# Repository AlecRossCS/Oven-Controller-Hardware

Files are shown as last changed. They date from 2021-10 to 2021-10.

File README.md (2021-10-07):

# Oven-Controller-Hardware
This project is about creating a controller for a heating element for a custom designed oven. The temperature needs to be controlled with industrial precision, so this baord contains a microcontroller as well as devices needed to interact with a thermocouple to precisely sense temperature, as well as a large power mosfet, which controls the power to the heating element to control the temperature with great accuracy. 

# Design

schematic

because of the supply shortage, the microcontroller was chosen as a RP2040 already made onto a Raspberry pi Pico board, because that board can be soldered onto another, as in this case, and both the RP2040, and my second choice of STM32F0 controllers are impossible to buy for any project currently. So buying a premade micro offers flexability as you can buy them in the quantities I need. the Micro interacts with both the sensor and mosfet, as well as capability to drive an LCD screen for display. A notable thing that is different here is that the mosfet does not use a large heatsink. That is not because it does not disspate much power, but because the newer technology on the market allows the Vishay thermal jumper to absorb and funnel much of the heat directly from the heat fin into the ground plane.

# Hardware
this was a standard layout, fairly straight forward. as components were placed and grouped, and then power connections ran, and then the rest of the connections, and then a gnd plane. 

the mockup

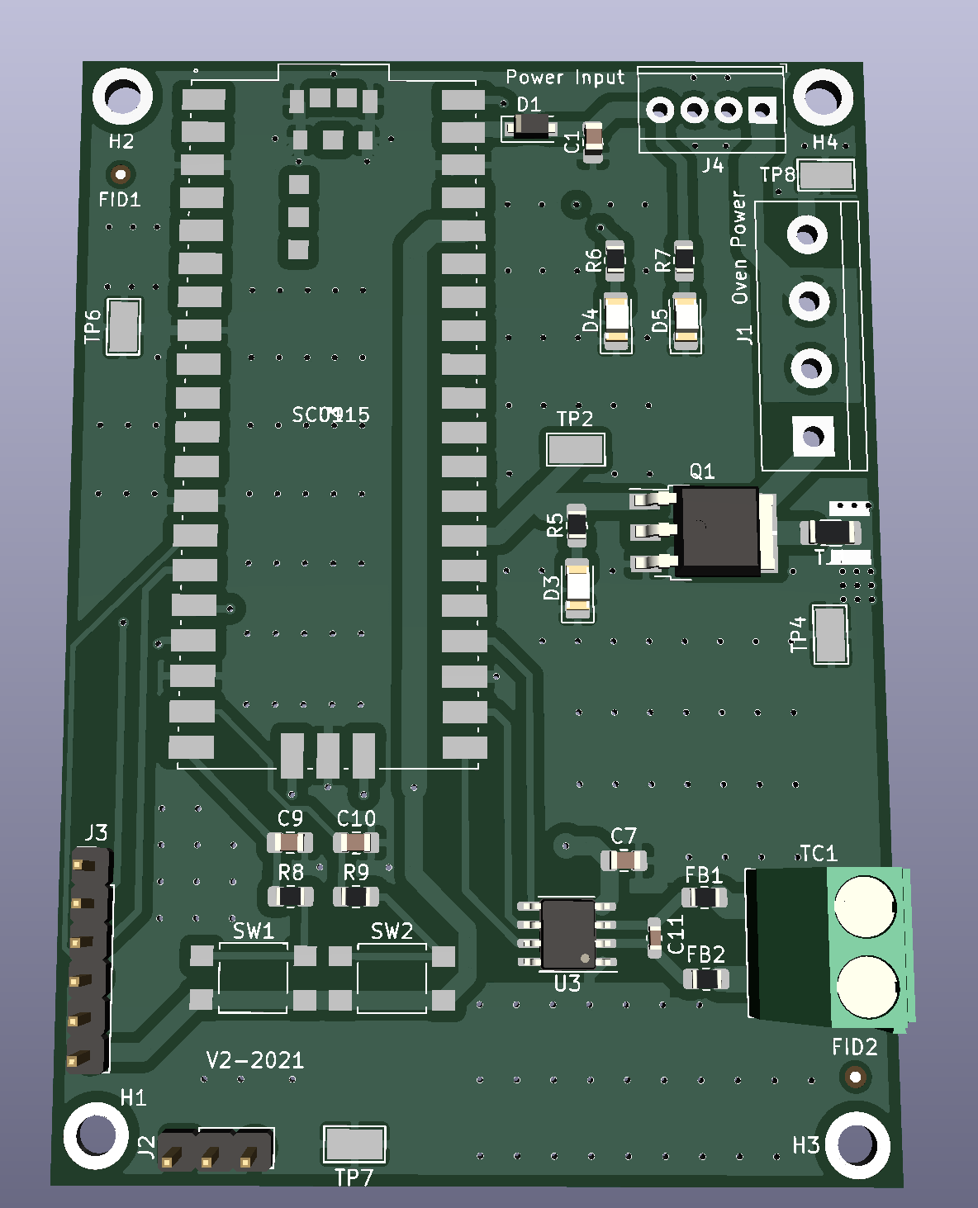
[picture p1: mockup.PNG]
mock


Version 1 has already been manufactured, and is currently in the firmware design stage. The major differences in design from version 1 is that it had SMPS on th board, which has now been broken into a separate board to allow for better space usage, a smaller footprint, and better thermal design for the SMPS.
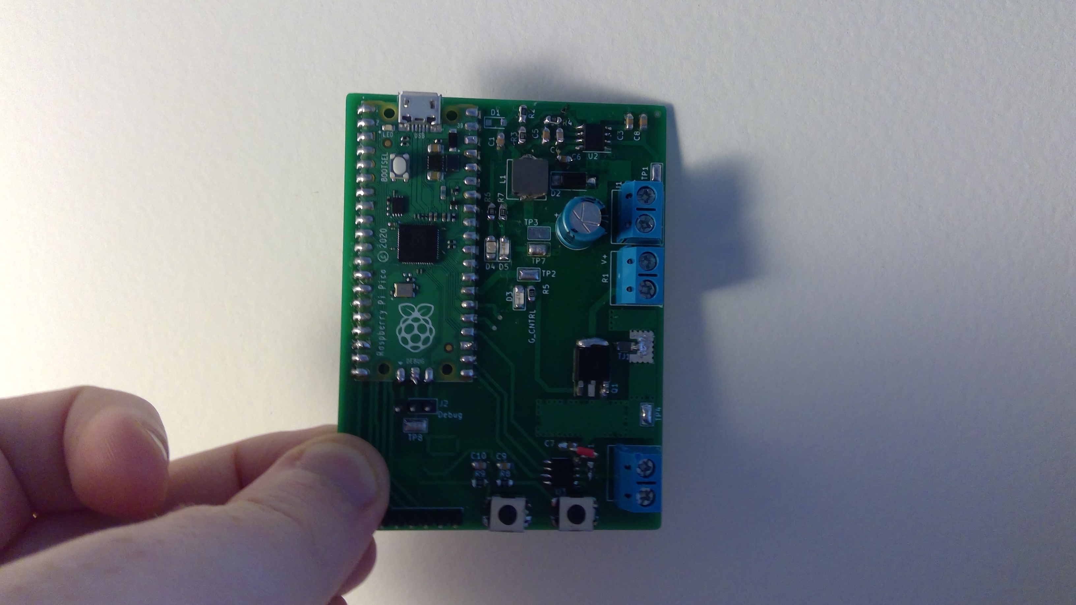
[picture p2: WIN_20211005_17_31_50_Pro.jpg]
actual_board


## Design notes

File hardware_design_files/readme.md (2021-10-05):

# hardware designfiles
all files designed in kicad, and simulated in Pspice.

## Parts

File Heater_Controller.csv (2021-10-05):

Source: | C:\Users\Alec\Documents\Classes\Electrical_Projects\Heater\Heater_Controller\Heater_Controller\Heater_Controller.sch
Date: | 8/18/2021 3:11
Tool: | Eeschema (5.1.10)-1
Generator: | C:\Program Files\KiCad\bin\scripting\plugins/bom_csv_grouped_by_value.py
Component Count: | 32
Individual Components:
Item | Qty | Reference(s) | Value | LibPart | Footprint | Datasheet | part#
0805B104J101CT | 1 | C1 | 100n | Device:C_Small | Capacitor_SMD:C_0805_2012Metric_Pad1.18x1.45mm_HandSolder | ~
25RX30100MCPA8X11.5 | 1 | C2 | 100u | Device:CP | Capacitor_THT:CP_Radial_D6.3mm_P2.50mm | ~
 |  | C3 | 5n | Device:C_Small | Capacitor_SMD:C_0805_2012Metric_Pad1.18x1.45mm_HandSolder | ~
 |  | C4 | 10p | Device:C_Small | Capacitor_SMD:C_0805_2012Metric_Pad1.18x1.45mm_HandSolder | ~
CGA4F2X7R2A222KT0Y0S | 5 | C5 | 2n | Device:C_Small | Capacitor_SMD:C_0805_2012Metric_Pad1.18x1.45mm_HandSolder | ~
0805B104J101CT | 1 | C6 | 100n | Device:C_Small | Capacitor_SMD:C_0805_2012Metric_Pad1.18x1.45mm_HandSolder | ~
0805B104J101CT | 1 | C7 | 100n | Device:C_Small | Capacitor_SMD:C_0805_2012Metric_Pad1.18x1.45mm_HandSolder | ~
0805B104J101CT | 1 | C8 | 100n | Device:C_Small | Capacitor_SMD:C_0805_2012Metric_Pad1.18x1.45mm_HandSolder | ~
US1DWF-7 | 1 | D1 | FS14 | Device:D_Schottky | Diode_SMD:D_SOD-123F | ~
SL34A-TP | 1 | D2 | SL34A | Device:D_Schottky | Diode_SMD:D_SMA_Handsoldering | ~
 |  | D3 | L171L-GC | Device:LED | LED_SMD:LED_0805_2012Metric_Pad1.15x1.40mm_HandSolder | ~
 |  | D4 | APTB1612SURKQBDC-F01 | Device:LED_Dual_AAC | LED_SMD:LED_Kingbright_AAA3528ESGCT | ~
FH1-200CK-B | 1 | F1 | Fuse | Device:Fuse | Fuse:Fuseholder_Cylinder-5x20mm_Stelvio-Kontek_PTF78_Horizontal_Open | ~
C4658 | 10 | HS1 | Heatsink_Pad | Mechanical:Heatsink_Pad | Heatsink:Heatsink_AAVID_573300D00010G_TO-263 | ~
C474881 | 5 | J1 | Screw_Terminal_01x02 | Connector:Screw_Terminal_01x02 | TerminalBlock_Phoenix:TerminalBlock_Phoenix_MKDS-1,5-2_1x02_P5.00mm_Horizontal | ~
5-146274-3 | 1 | J2 | Conn_01x03_Male | Connector:Conn_01x03_Male | Connector_PinHeader_2.54mm:PinHeader_1x03_P2.54mm_Vertical | ~
 |  | J3 | Conn_01x06 | Connector_Generic:Conn_01x06 | Connector_PinHeader_2.54mm:PinHeader_1x06_P2.54mm_Vertical | ~
 |  | L1 | 12uH | Device:L | Inductor_THT:L_Axial_L7.0mm_D3.3mm_P10.16mm_Horizontal_Fastron_MICC | ~
FDD8447L | 1 | Q1 | FDD8447L | Device:Q_NMOS_GDS | Package_TO_SOT_SMD:TO-252-3_TabPin2 | ~
RT0805FRE0710KL | 50 | R2 | 10k | Device:R | Resistor_SMD:R_0805_2012Metric_Pad1.20x1.40mm_HandSolder | ~
RT0805BRB072KL | 1 | R3 | 2k | Device:R | Resistor_SMD:R_0805_2012Metric_Pad1.20x1.40mm_HandSolder | ~
 | 1 | R4 | 14k | Device:R | Resistor_SMD:R_0805_2012Metric_Pad1.20x1.40mm_HandSolder | ~
ERA6AEB102V | 1 | R5 | 1k | Device:R | Resistor_SMD:R_0805_2012Metric_Pad1.20x1.40mm_HandSolder | ~
ERA6AEB102V | 1 | R6 | 1k | Device:R | Resistor_SMD:R_0805_2012Metric_Pad1.20x1.40mm_HandSolder | ~
ERA6AEB102V | 1 | R7 | 1k | Device:R | Resistor_SMD:R_0805_2012Metric_Pad1.20x1.40mm_HandSolder | ~
 | 2 | U1 | SC0915 | Heater_Controller-rescue:SC0915-2021-08-14_07-35-25 | footprints:SC0915-Up
TPS54331DR | 1 | U2 | TPS54331D | Heater_Controller-rescue:TPS54331D-2021-08-15_07-00-47 | Package_SO:SOIC-8_3.9x4.9mm_P1.27mm |  | TPS54331D
MAX31855KASA+T | 1 | U3 | MAX31855KASA | Sensor_Temperature:MAX31855KASA | Package_SO:SOIC-8_3.9x4.9mm_P1.27mm | http://datasheets.maximintegrated.com/en/ds/MAX31855.pdf
Collated Components:
Item | Qty | Reference(s) | Value | LibPart | Footprint | Datasheet | part#
1 | 4 | C1, C6, C7, C8 | 100n | Device:C_Small | Capacitor_SMD:C_0805_2012Metric_Pad1.18x1.45mm_HandSolder | ~
2 | 1 | C2 | 100u | Device:CP | Capacitor_THT:CP_Radial_D6.3mm_P2.50mm | ~
3 | 1 | C3 | 5n | Device:C_Small | Capacitor_SMD:C_0805_2012Metric_Pad1.18x1.45mm_HandSolder | ~
4 | 1 | C4 | 10p | Device:C_Small | Capacitor_SMD:C_0805_2012Metric_Pad1.18x1.45mm_HandSolder | ~
5 | 1 | C5 | 2n | Device:C_Small | Capacitor_SMD:C_0805_2012Metric_Pad1.18x1.45mm_HandSolder | ~
6 | 1 | D1 | FS14 | Device:D_Schottky | Diode_SMD:D_SOD-123F | ~
7 | 1 | D2 | SL34A | Device:D_Schottky | Diode_SMD:D_SMA_Handsoldering | ~
8 | 1 | D3 | L171L-GC | Device:LED | LED_SMD:LED_0805_2012Metric_Pad1.15x1.40mm_HandSolder | ~
9 | 1 | D4 | APTB1612SURKQBDC-F01 | Device:LED_Dual_AAC | LED_SMD:LED_Kingbright_AAA3528ESGCT | ~
10 | 1 | F1 | Fuse | Device:Fuse | Fuse:Fuseholder_Cylinder-5x20mm_Stelvio-Kontek_PTF78_Horizontal_Open | ~
11 | 2 | FID1, FID2 | Fiducial | Mechanical:Fiducial | Fiducial:Fiducial_0.75mm_Mask1.5mm | ~
12 | 1 | HS1 | Heatsink_Pad | Mechanical:Heatsink_Pad | Heatsink:Heatsink_AAVID_573300D00010G_TO-263 | ~
13 | 1 | J1 | Screw_Terminal_01x02 | Connector:Screw_Terminal_01x02 | TerminalBlock_Phoenix:TerminalBlock_Phoenix_MKDS-1,5-2_1x02_P5.00mm_Horizontal | ~
14 | 1 | J2 | Conn_01x03_Male | Connector:Conn_01x03_Male | Connector_PinHeader_2.54mm:PinHeader_1x03_P2.54mm_Vertical | ~
15 | 1 | J3 | Conn_01x06 | Connector_Generic:Conn_01x06 | Connector_PinHeader_2.54mm:PinHeader_1x06_P2.54mm_Vertical | ~
16 | 1 | L1 | 12uH | Device:L | Inductor_THT:L_Axial_L7.0mm_D3.3mm_P10.16mm_Horizontal_Fastron_MICC | ~
17 | 1 | Q1 | FDD8447L | Device:Q_NMOS_GDS | Package_TO_SOT_SMD:TO-252-3_TabPin2 | ~
18 | 1 | R1 | R | Device:R | TerminalBlock_Phoenix:TerminalBlock_Phoenix_MKDS-1,5-2_1x02_P5.00mm_Horizontal | ~
19 | 1 | R2 | 10k | Device:R | Resistor_SMD:R_0805_2012Metric_Pad1.20x1.40mm_HandSolder | ~
20 | 1 | R3 | 2k | Device:R | Resistor_SMD:R_0805_2012Metric_Pad1.20x1.40mm_HandSolder | ~
21 | 1 | R4 | 14k | Device:R | Resistor_SMD:R_0805_2012Metric_Pad1.20x1.40mm_HandSolder | ~
22 | 3 | R5, R6, R7 | 1k | Device:R | Resistor_SMD:R_0805_2012Metric_Pad1.20x1.40mm_HandSolder | ~
23 | 1 | TC1 | Thermocouple | Device:Thermocouple | TerminalBlock_Phoenix:TerminalBlock_Phoenix_MKDS-1,5-2_1x02_P5.00mm_Horizontal | ~
24 | 1 | U1 | SC0915 | Heater_Controller-rescue:SC0915-2021-08-14_07-35-25 | footprints:SC0915-Up
25 | 1 | U2 | TPS54331D | Heater_Controller-rescue:TPS54331D-2021-08-15_07-00-47 | Package_SO:SOIC-8_3.9x4.9mm_P1.27mm |  | TPS54331D
26 | 1 | U3 | MAX31855KASA | Sensor_Temperature:MAX31855KASA | Package_SO:SOIC-8_3.9x4.9mm_P1.27mm | http://datasheets.maximintegrated.com/en/ds/MAX31855.pdf

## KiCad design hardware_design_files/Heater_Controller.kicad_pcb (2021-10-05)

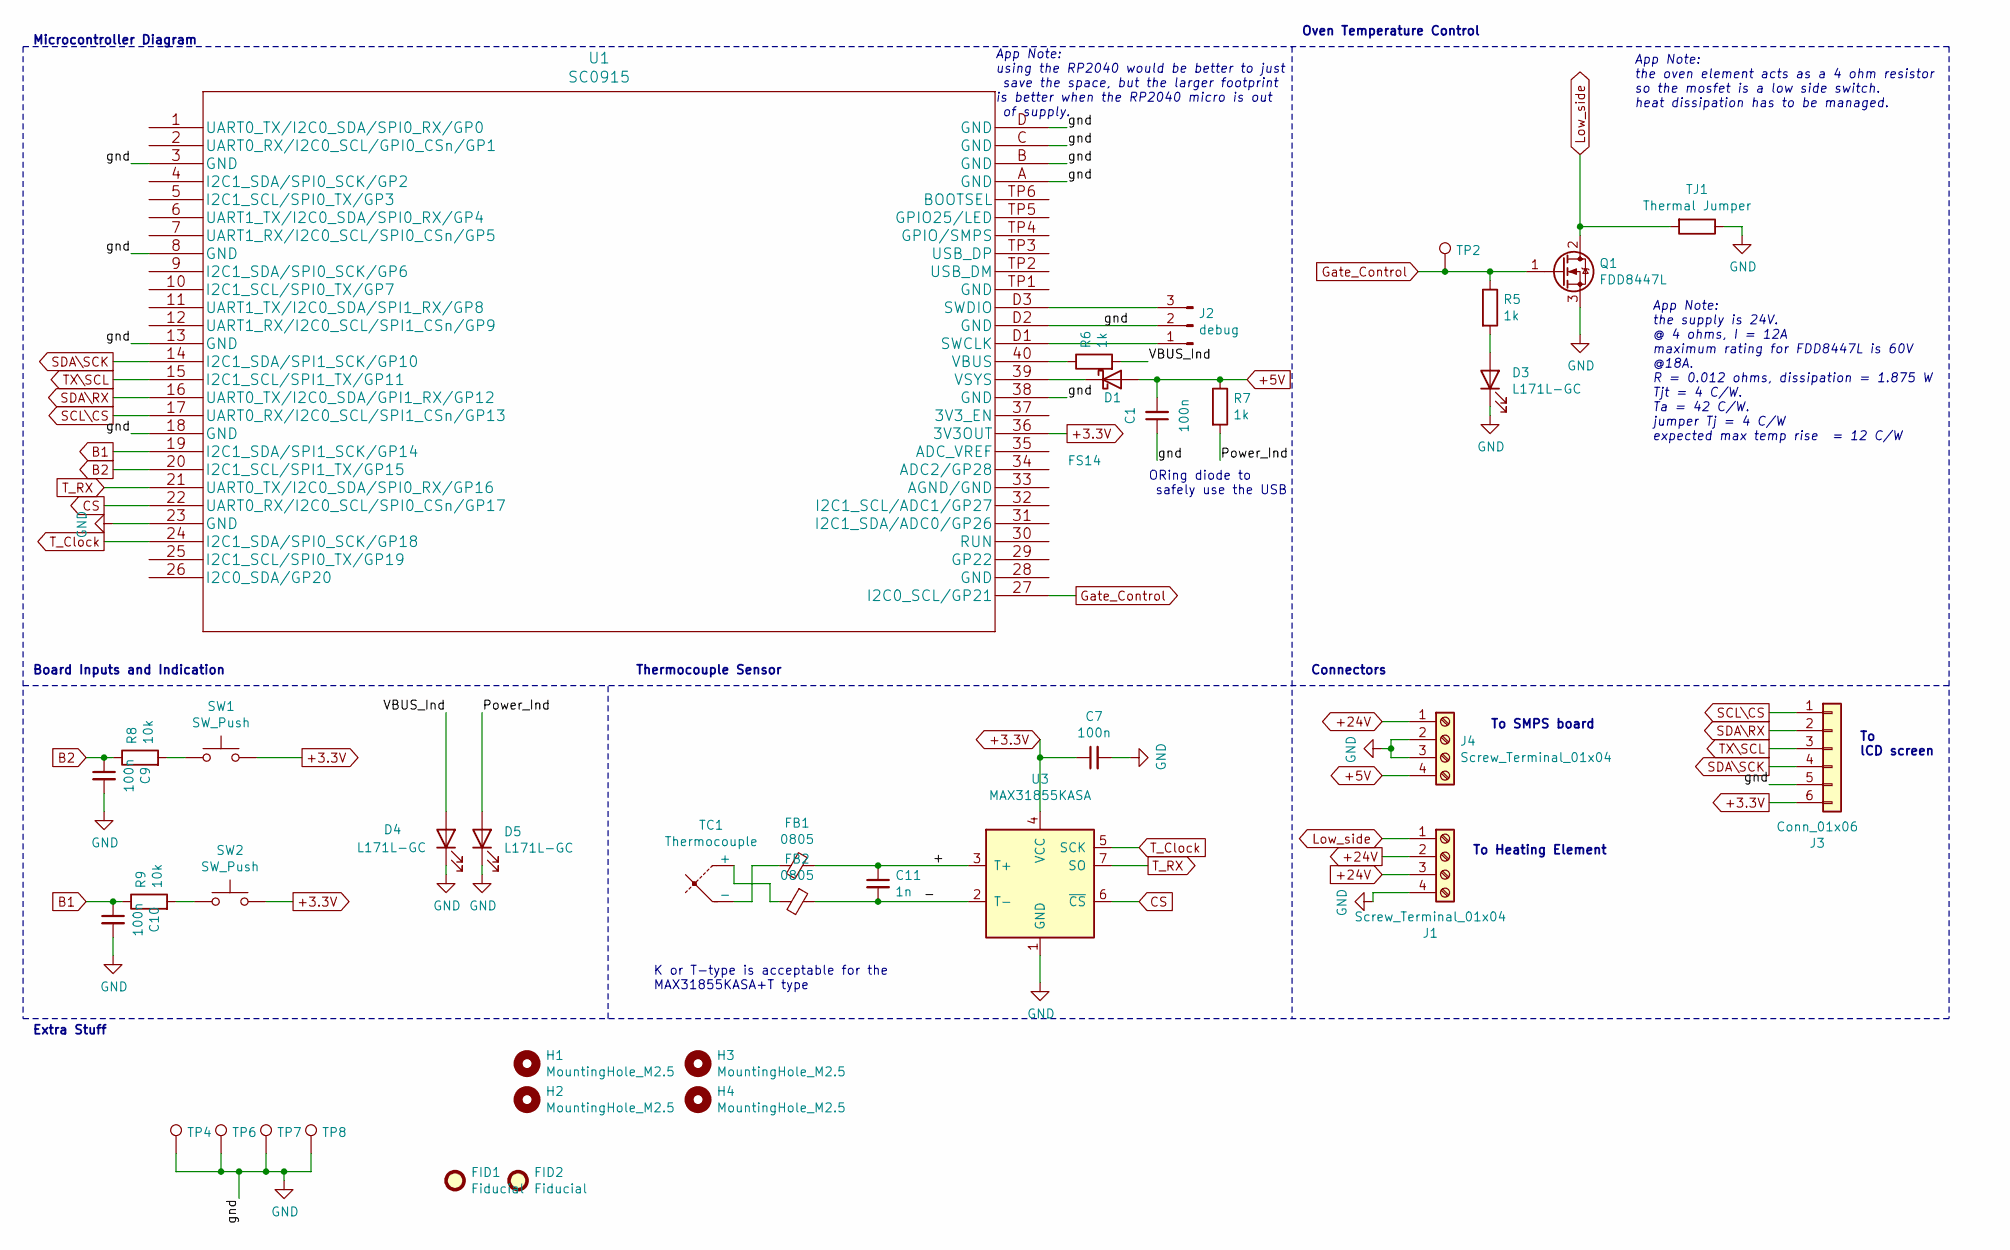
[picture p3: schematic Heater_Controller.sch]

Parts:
C1, C7, C9, C10: 100n; C_0805_2012Metric_Pad1.18x1.45mm_HandSolder
C11: 1n; C_0603_1608Metric_Pad1.08x0.95mm_HandSolder
D1: FS14; D_SOD-123F
D3, D4, D5: L171L-GC; LED_1206_3216Metric_Pad1.42x1.75mm_HandSolder
FB1, FB2: 0805; R_0805_2012Metric_Pad1.20x1.40mm_HandSolder
FID1, FID2: Fiducial; Fiducial_0.75mm_Mask1.5mm
H1, H2, H3, H4: MountingHole_M2.5; MountingHole_2.7mm_M2.5_ISO7380_Pad_TopBottom
J1: Screw_Terminal_01x04; TerminalBlock_bornier-4_P5.08mm
J2: debug; PinHeader_1x03_P2.54mm_Vertical
J3: Conn_01x06; PinHeader_1x06_P2.54mm_Vertical
J4: Screw_Terminal_01x04; TerminalBlock_TE_282834-4_1x04_P2.54mm_Horizontal
Q1: FDD8447L; TO-252-3_TabPin2
R5, R6, R7: 1k; R_0805_2012Metric_Pad1.20x1.40mm_HandSolder
R8, R9: 10k; R_0805_2012Metric_Pad1.20x1.40mm_HandSolder
SW1, SW2: SW_Push; SW_SPST_TL3305C
TC1: Thermocouple; TerminalBlock_Phoenix_MKDS-1,5-2_1x02_P5.00mm_Horizontal
TJ1: Thermal Jumper; R_1206_3216Metric_Pad1.30x1.75mm_HandSolder
TP2, TP4, TP6, TP7, TP8: TestPoint_Keystone_5019_Minature
U1: SC0915; SC0915-Up
U3: MAX31855KASA; SOIC-8_3.9x4.9mm_P1.27mm

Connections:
+3.3V: C7.1, J3.6, SW1.2, SW2.2, U1.36 (3V3OUT), U3.4 (VCC)
+5V: C1.2, D1.2 (A), J4.4, R7.1
+24V: J1.2, J1.3, J4.1
/+: C11.1, FB1.2, U3.3 (T+)
/-: C11.2, FB2.1, U3.2 (T-)
/Power_Ind: D5.2 (A), R7.2
/VBUS_Ind: D4.2 (A), R6.2
B1: C10.1, R9.1, U1.19 (I2C1_SDA/SPI1_SCK/GP14)
B2: C9.1, R8.1, U1.20 (I2C1_SCL/SPI1_TX/GP15)
CS: U1.22 (UART0_RX/I2C0_SCL/SPI0_CSn/GP17), U3.6 (~CS~)
GND: C1.1, C7.2, C9.2, C10.2, D3.1 (K), D4.1 (K), D5.1 (K), J1.4, J2.2, J3.5, J4.2, J4.3, Q1.3 (S), TJ1.1, TP4.1, TP6.1, TP7.1, TP8.1, U1.3 (GND), U1.8 (GND), U1.13 (GND), U1.18 (GND), U1.23 (GND), U1.38 (GND), U1.A (GND), U1.B (GND), U1.C (GND), U1.D (GND), U1.D2 (GND), U3.1 (GND)
Gate_Control: Q1.1 (G), R5.1, TP2.1, U1.27 (I2C0_SCL/GP21)
Low_side: J1.1, Q1.2 (D), TJ1.2
unnamed: D1.1 (K), U1.39 (VSYS)
unnamed: D3.2 (A), R5.2
unnamed: FB1.1, TC1.2 (-)
unnamed: FB2.2, TC1.1 (+)
unnamed: J2.1, U1.D1 (SWCLK)
unnamed: J2.3, U1.D3 (SWDIO)
unnamed: R6.1, U1.40 (VBUS)
unnamed: R8.2, SW1.1
unnamed: R9.2, SW2.1
SCL\CS: J3.1, U1.17 (UART0_RX/I2C0_SCL/SPI1_CSn/GP13)
SDA\RX: J3.2, U1.16 (UART0_TX/I2C0_SDA/GPI1_RX/GP12)
SDA\SCK: J3.4, U1.14 (I2C1_SDA/SPI1_SCK/GP10)
TX\SCL: J3.3, U1.15 (I2C1_SCL/SPI1_TX/GP11)
T_Clock: U1.24 (I2C1_SDA/SPI0_SCK/GP18), U3.5 (SCK)
T_RX: U1.21 (UART0_TX/I2C0_SDA/SPI0_RX/GP16), U3.7 (SO)

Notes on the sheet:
K or T-type is acceptable for the MAX31855KASA+T type
ORing diode to safely use the USB
Microcontroller Diagram
Board Inputs and Indication
Thermocouple Sensor
App Note: using the RP2040 would be better to just save the space, but the larger footprint is better when the RP2040 micro is out of supply.
Oven Temperature Control
App Note: the oven element acts as a 4 ohm resistor so the mosfet is a low side switch. heat dissipation has to be managed.
App Note: the supply is 24V. @ 4 ohms, I = 12A maximum rating for FDD8447L is 60V @18A. R = 0.012 ohms, dissipation = 1.875 W Tjt = 4 C/W. Ta = 42 C/W. jumper Tj = 4 C/W expected max temp rise = 12 C/W
Connectors
To SMPS board
To Heating Element
To lCD screen
Extra Stuff

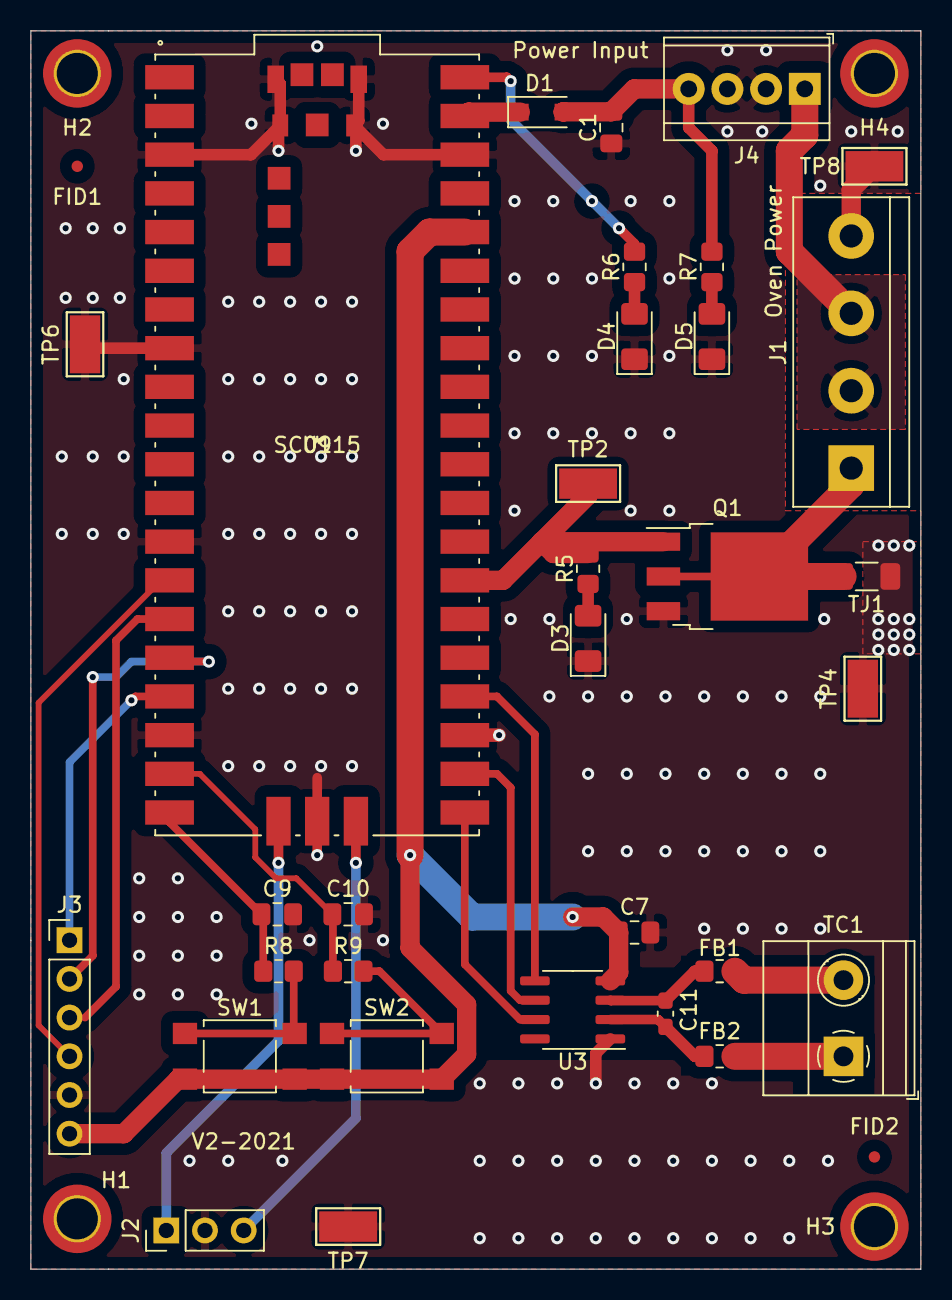
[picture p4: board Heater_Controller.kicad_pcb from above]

Board: 2 copper layers, 58.4 x 81.3 mm, 38 parts (0 on the bottom side), 28 nets.

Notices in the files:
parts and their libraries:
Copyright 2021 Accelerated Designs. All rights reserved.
